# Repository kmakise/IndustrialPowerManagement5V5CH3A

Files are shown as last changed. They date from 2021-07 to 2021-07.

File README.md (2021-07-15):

# IndustrialPowerManagement5V5CH3A
基于STM32的电源控制器 使用LinerTechnology方案 Dwin屏交互 电流监控工作时间控制
# 图片
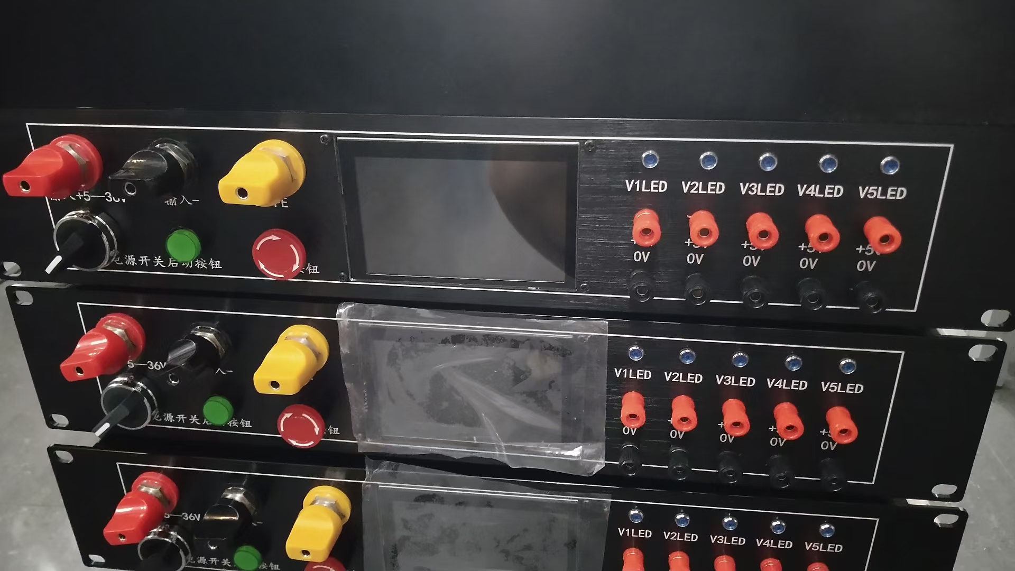
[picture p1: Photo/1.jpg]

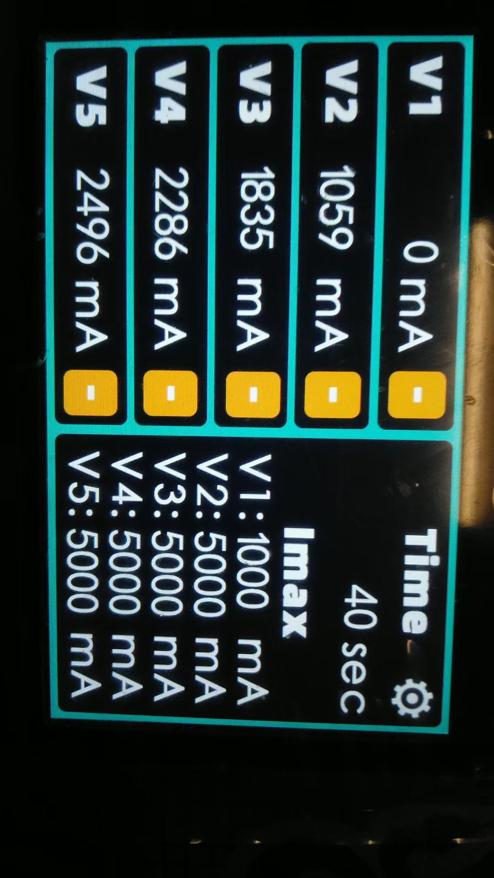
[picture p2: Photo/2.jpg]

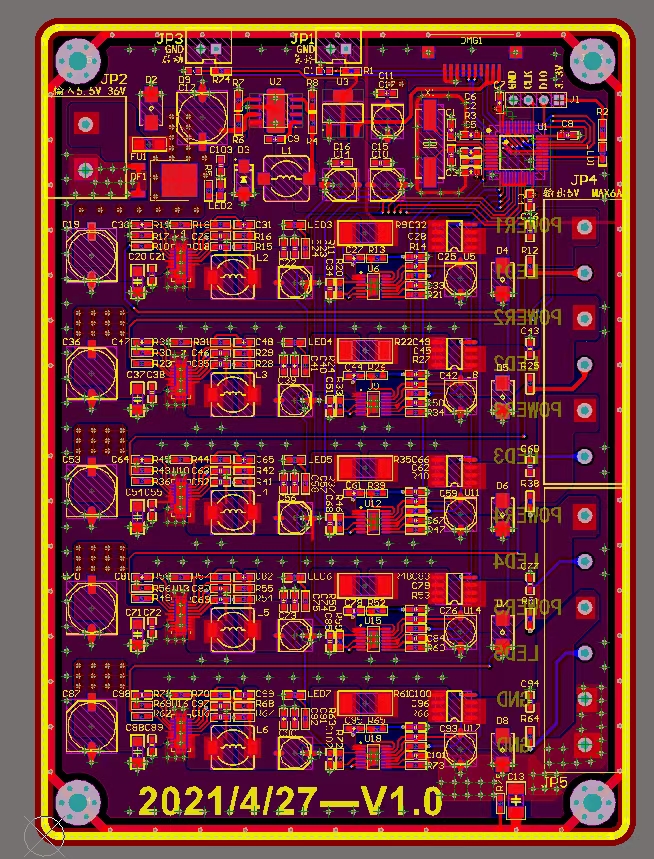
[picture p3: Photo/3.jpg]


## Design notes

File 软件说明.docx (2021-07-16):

# 1. 目录说明

目录\文件 名称 | 内容
DwinGUI\DWIN_SET | Dwin下载文件目录
DwinGUI\img | 界面图片目录
DwinGUI\DWprj.hmi | DGUSII工程
MCUProject\MDK-ARM\PowerManager.uvprojx | Stm32 MDK工程
MCUProject\PowerManager.ioc | Stm32 Cubemx工程
MCUProject\MDK-ARM\PowerManager\PowerManager.hex | STM32 Hex下载文件

# 2. 程序下载

## 2.1 DWIN

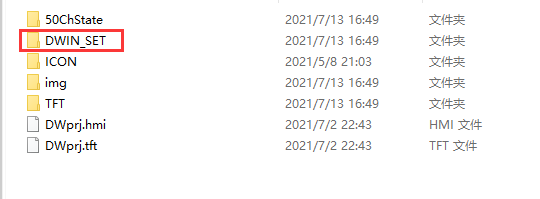
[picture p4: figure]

将 DWIN_SET 文件夹复制到SD卡根目录通过 SD 卡下载到屏里。顺序为：屏掉电——插卡——上电——蓝屏读 取 SD 卡内容，下载完成显示“SD Card Process …END！”——掉电、退出 SD 卡——上电。

## 2.2 STM32

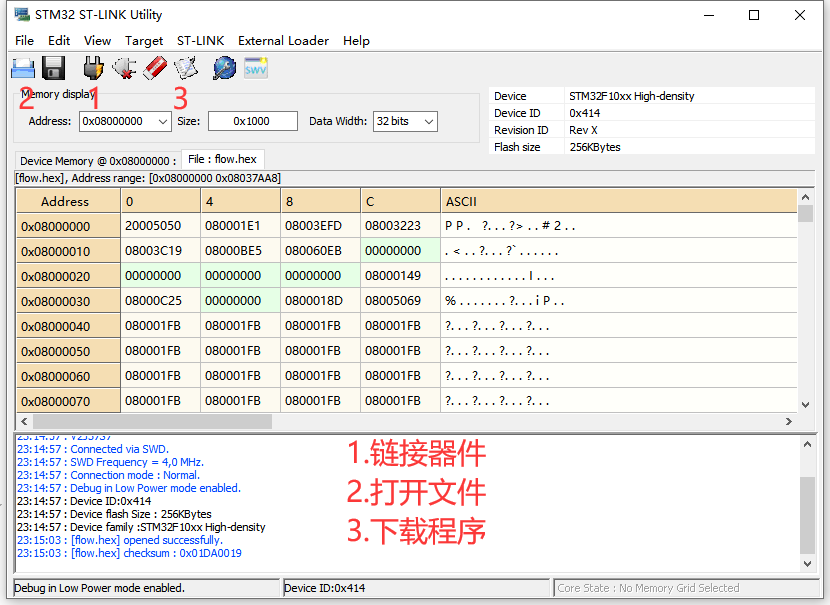
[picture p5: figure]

# 3. 电流校准

## 3.1 清除参数

将电流计算比例系数改为1.0后编译下载开始运行 Task01.c line77-81

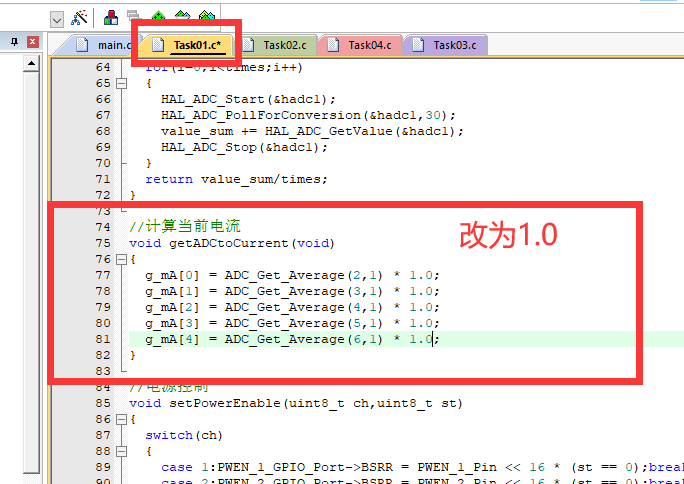
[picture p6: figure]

## 3.2 计算参数

例 修正系数=真实值/显示值 例：(实)2500/(显)1943=1.2866700977869274318

然后依次写入对应通道

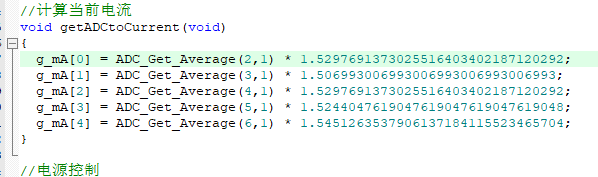
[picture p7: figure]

## 3.2 写入参数

重新编译并下载完成电流校准

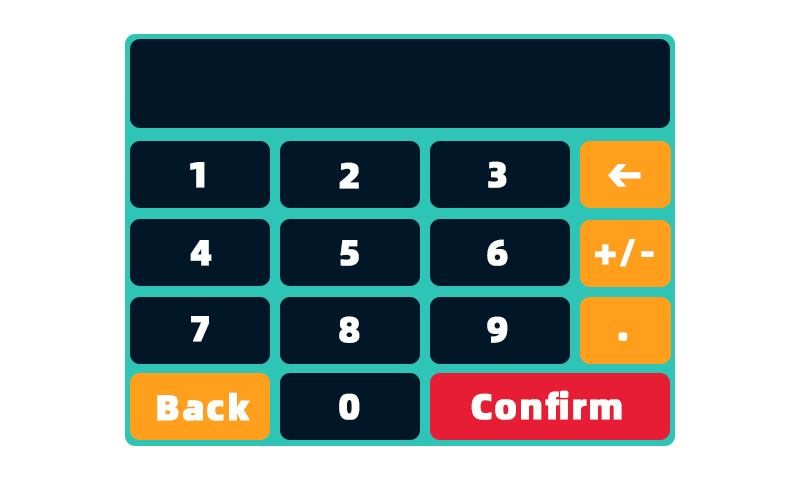
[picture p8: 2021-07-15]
DwinGUI/img/20键盘.png

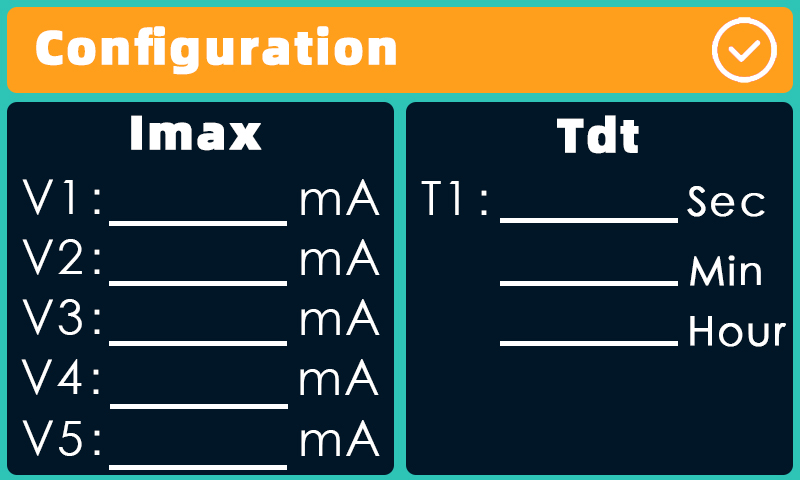
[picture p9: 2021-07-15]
DwinGUI/img/1Config.jpg

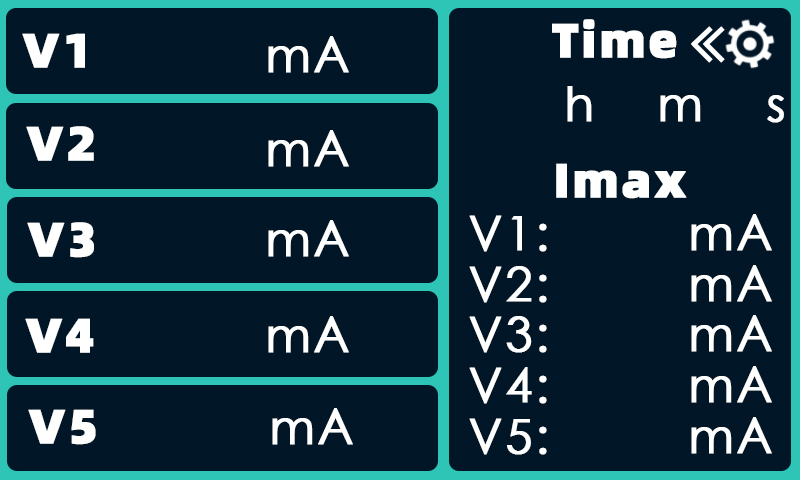
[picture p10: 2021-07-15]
DwinGUI/img/0主页面.jpg

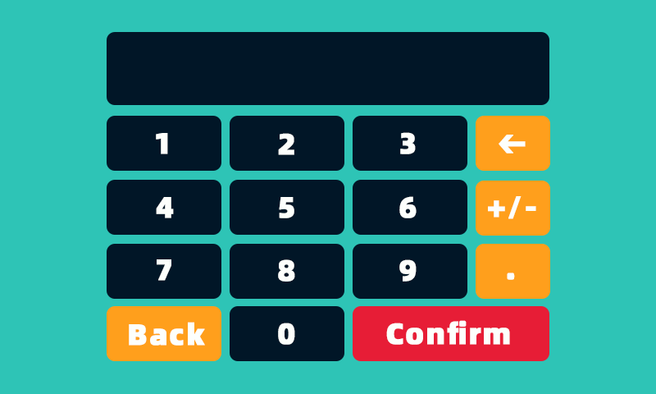
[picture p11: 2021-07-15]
DwinGUI/DWIN_SET/20键盘.png

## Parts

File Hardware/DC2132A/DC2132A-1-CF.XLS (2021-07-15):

Item | Qty | Reference | Part Description | Manufacturer / Part #
REQUIRED CIRCUIT COMPONENTS
1 | 12 | C3,C5,C6,C7,C9,C10,C11,C19,C20,C22,C27,C28 | Cap., X5R 10uF 50V 20% 1210 | TAIYO YUDEN UMK325BJ106MM-T
2 | 1 | C4 | Cap., X5R 0.1µF 50V 10% 0603 | TDK C1608X5R1H104K
3 | 1 | C12 | Cap., X5R 1uF 50V 10% 0603 | TDK C1608X5R1H105K
4 | 1 | C13 | Cap., NPO 1nF 25V 5% 0603 | AVX 06033A102JAT2A
5 | 1 | C14 | Cap., X5R 1µF 25V 10% 0603 | TDK C1608X5R1E105K
6 | 1 | C15 | Cap., X7R 0.1µF 25V 10% 0603 | AVX 06033C104KAT2A
7 | 2 | C17,C23 | Cap., X7R 0.01µF 100V 10% 0603 | AVX 06031C103KAT2A
8 | 1 | C21 | Cap., X7R 1µF 50V 10% 0805 | MURATA GRM21BR71H105KA12L
9 | 1 | C25 | Cap., X7R 1µF 16V 10% 0603 | MURATA GCM188R71C105KA64L
10 | 1 | C26 | Cap., X5R 10µF 6.3V 20% 0603 | TDK C1608X5R0J106M
11 | 1 | C29 | Cap., Alum. Elect. 100µF 35V ±20% F80 | Nippon Chemi-Con EMZA350ADA101MF80G
12 | 1 | D5 | Schottky Diode, 1A/40V SMA | DIODES/ZETEX B140-13-F
13 | 1 | L1 | Inductor, 5.5µH | WURTH ELECTRONIK 744325550
14 | 1 | L2 | Inductor, 470µH ±10% 1210 | MURATA LQH32CN471K23L
15 | 1 | Q1 | Transistor, NPN SOT23 | DIODES/ZETEX FMMT493TA
16 | 2 | Q2,Q3 | Transistor., PNP SOT23 | DIODES/ZETEX MMBT3906-7-F
17 | 1 | Q4 | MOSFET, Single P-Chan. 60V SOT-23 | VISHAY SI2309CDS-T1-GE3
18 | 1 | Q5 | Transistor, NPN SOT23 | CENTRAL SEMI. CORP. CMST3904TR
19 | 1 | R2 | Res., Chip 549 OHMS 0.10W 1% 0603 | VISHAY CRCW0603549RFKEA
20 | 1 | R5 | Res., Chip 499K 0.10W 1% 0603 | VISHAY CRCW0603499KFKEA
21 | 1 | R6 | Res., Chip 54.9K 0.10W 1% 0603 | VISHAY CRCW060354K9FKEA
22 | 2 | R7,R23 | Res., 0.010 OHMS 0.125W 1% 0805 | VISHAY WSL0805R0100FEA
23 | 1 | R8 | Res., Chip 3.92K 0.10W 1% 0603 | VISHAY CRCW06033K92FKEA
24 | 2 | R9,R26 | Res., Chip 10K 0.25W 5% 1206 | VISHAY CRCW120610K0JNED
25 | 1 | R12 | Res., Chip 100 OHMS 0.10W 1% 0603 | VISHAY CRCW0603100RFKEA
26 | 2 | R14,R18 | Res., Chip 4.99K 0.10W 1% 0603 | VISHAY CRCW06034K99FKEA
27 | 3 | R15,R29,R37 | Res., Chip 1.00K 0.10W 1% 0603 | VISHAY CRCW06031K00FKEA
28 | 2 | R17,R30 | Res., Chip 10.0K 0.10W 1% 0603 | VISHAY CRCW060310K0FKEA
29 | 1 | R20 | Res., Chip 60.4K 0.10W 1% 0603 | VISHAY CRCW060360K4FKEA
30 | 2 | R21,R38 | Res., Chip 100K 0.10W 1% 0603 | VISHAY CRCW0603100KFKEA
31 | 1 | R22 | Res., Chip 200 OHMS 0.125W 1% 0805 | VISHAY CRCW0805200RFKEA
32 | 1 | R24 | Res., Chip 47.5K 0.10W 1% 0603 | VISHAY CRCW060347K5FKEA
33 | 1 | R27 | Res., Chip 73.2K 0.10W 1% 0603 | VISHAY CRCW060373K2FKEA
34 | 1 | R28 | Res., Chip 11.3K 0.10W 1% 0603 | VISHAY CRCW060311K3FKEA
35 | 1 | R31 | Pot. 1 Turn 10K ±10% | BOURNS 91A1A-B28-A15L
36 | 1 | R32 | Pot. 1 Turn 5K ±10% | BOURNS 91A1A-B28-A13L
37 | 1 | R41 | Res., Chip 1K 0.10W 5% 0603 | VISHAY CRCW06031K00JNEA
38 | 1 | R42 | Res., Chip 1.47M 0.10W 1% 0603 | VISHAY CRCW06031M47FKEA
39 | 1 | R43 | Res., Chip 10K 0.10W 5% 0603 | VISHAY CRCW060310K0JNEA
40 | 1 | R44 | Res., Chip 280K 0.10W 1% 0603 | VISHAY CRCW0603280KFKEA
41 | 1 | R45 | Res., Chip 806K 0.10W 1% 0603 | VISHAY CRCW0603806KFKEA
42 | 1 | R47 | Res., Chip 5.1K 0.10W 5% 0603 | Vishay CRCW06035K10JNEA
43 | 1 | R48 | Res., Chip 2.7K 0.10W 5% 0603 | Vishay CRCW06032K70JNEA
44 | 2 | U1,U2 | I.C., Linear Reg. DD-R(07)(1462-REVF) | LINEAR TECH. CORP. LT3081ER#PBF
45 | 1 | U3 | I.C., Regulator QFN(28)(UDE)3MMX6MM | LINEAR TECH. CORP. LT8612EUDE#PBF
46 | 1 | U4 | I.C., DC/DC Converter DFN(08)(DD)3MMX3MM | LINEAR TECH. CORP. LT3092EDD#PBF
47 | 1 | U5 | I.C., Step-Down Converter DFN(08)(DD)3MMX3MM | LINEAR TECH. CORP. LTC3632EDD#PBF
OPTIONAL CIRCUIT COMPONENTS
1 | 1 | C8 | Cap., Alum 22µF 63V 25% | SUN Elect. Ind. 63CE22BS
2 | 0 | C16,C30 | OPTIONAL 0603
3 | 0 | C24 | OPTIONAL 1210
4 | 1 | D4 | LED, GRN | OSRAM Opto Semi. LG L29K-G2J1-24-Z
5 | 0 | R6,R19,R25,R46 | OPTIONAL 0603
6 | 1 | R13 | Res., Chip 549 OHMS 0.10W 1% 0603 | VISHAY CRCW0603549RFKEA
7 | 1 | R16 | Res/Jumper, Chip 0 Ohm 0.25W 0603 | VISHAY CRCW06030000Z0EA
8 | 0 | R33 | OPTIONAL Pot. 10 Turns 10K | BOURNS 3950S-1-103L
9 | 0 | R34 | OPTIONAL Pot. 10 Turns 5K | BOURNS 3950S-1-502L
HARDWARE
1 | 6 | E1,E2,E3,E4,E5,E6 | Turret, Testpoint | MILL-MAX 2501-2-00-80-00-00-07-0
2 | 2 | E7,E8 | Turret, Testpoint | MILL-MAX 2308-2-00-80-00-00-07-0
3 | 1 | JP1 | Headers, Dbl. Row 2 x 3 2mm Ctrs. | SAMTEC TMM-103-02-L-D
4 | 4 | J1,J2,J3,J4 | Connector, Banana Jack | KEYSTONE 575-4
5 | 1 | S1 | Switch Toggle, SPDT | Philmore, 30-10002B
6 | 1 | XJP1 | Shunt, 2mm Ctrs. | SAMTEC 2SN-BK-G

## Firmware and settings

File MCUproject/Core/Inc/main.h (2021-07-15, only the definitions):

#define IMON_1_Pin GPIO_PIN_2
#define IMON_1_GPIO_Port GPIOA
#define IMON_2_Pin GPIO_PIN_3
#define IMON_2_GPIO_Port GPIOA
#define IMON_3_Pin GPIO_PIN_4
#define IMON_3_GPIO_Port GPIOA
#define IMON_4_Pin GPIO_PIN_5
#define IMON_4_GPIO_Port GPIOA
#define IMON_5_Pin GPIO_PIN_6
#define IMON_5_GPIO_Port GPIOA
#define INP_1_Pin GPIO_PIN_7
#define INP_1_GPIO_Port GPIOA
#define INP_2_Pin GPIO_PIN_0
#define INP_2_GPIO_Port GPIOB
#define INP_3_Pin GPIO_PIN_1
#define INP_3_GPIO_Port GPIOB
#define INP_4_Pin GPIO_PIN_2
#define INP_4_GPIO_Port GPIOB
#define INP_5_Pin GPIO_PIN_10
#define INP_5_GPIO_Port GPIOB
#define RUN_LED_Pin GPIO_PIN_8
#define RUN_LED_GPIO_Port GPIOA
#define SW1_Pin GPIO_PIN_11
#define SW1_GPIO_Port GPIOA
#define SW2_Pin GPIO_PIN_12
#define SW2_GPIO_Port GPIOA
#define PWEN_1_Pin GPIO_PIN_5
#define PWEN_1_GPIO_Port GPIOB
#define PWEN_2_Pin GPIO_PIN_6
#define PWEN_2_GPIO_Port GPIOB
#define PWEN_3_Pin GPIO_PIN_7
#define PWEN_3_GPIO_Port GPIOB
#define PWEN_4_Pin GPIO_PIN_8
#define PWEN_4_GPIO_Port GPIOB
#define PWEN_5_Pin GPIO_PIN_9
#define PWEN_5_GPIO_Port GPIOB

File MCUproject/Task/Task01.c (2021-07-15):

/**
  ******************************************************************************
  * File Name          : Task01.c
  * Description        : Code for freeRTOS Task01 Application
  ******************************************************************************
  * @author  kmakise
  * @version V1.0.0
  * @date    2021-6-2
  * @brief   Power Management Main Logic
	******************************************************************************
  * @attention
  * <h2><center>&copy; Copyright (c) kmakise
  * All rights reserved.
  *
  *
  ******************************************************************************
  */
/* Includes ------------------------------------------------------------------*/
#include "main.h"
#include "cmsis_os.h"
#include "adc.h"
#include "usart.h"
#include "gpio.h"
#include "Task01.h"
#include "Task02.h"
#include "Task03.h"
#include "Task04.h"

/*Global Data Space ----------------------------------------------------------*/

uint16_t g_mA[5] = {0,0,0,0,0};
uint16_t g_chst[5] = {WARITING,WARITING,WARITING,WARITING,WARITING};
uint16_t g_state = 0; //0 等待状态 1运行状态 2超限状态 3急停状态

/*Driver Function ------------------------------------------------------------*/

uint8_t getRunPress(void)
{
	return (SW2_GPIO_Port->IDR & SW2_Pin) == 0;
}
uint8_t getStopPress(void)
{
	return (SW1_GPIO_Port->IDR & SW1_Pin) == 0;
}

//ch(1-6Chnnal),times(读取次数)
uint32_t ADC_Get_Average(uint8_t ch,uint8_t times)
{
	ADC_ChannelConfTypeDef sConfig;		//通道初始化
	uint32_t value_sum=0;	
	uint8_t i;
	switch(ch)							//选择ADC通道
	{
		case 1:sConfig.Channel = ADC_CHANNEL_1;break;	
		case 2:sConfig.Channel = ADC_CHANNEL_2;break;
		case 3:sConfig.Channel = ADC_CHANNEL_3;break;
		case 4:sConfig.Channel = ADC_CHANNEL_4;break;
		case 5:sConfig.Channel = ADC_CHANNEL_5;break;
		case 6:sConfig.Channel = ADC_CHANNEL_6;break;
	}
	sConfig.SamplingTime = ADC_SAMPLETIME_239CYCLES_5;
	sConfig.Rank = 1;
	HAL_ADC_ConfigChannel(&hadc1,&sConfig);											
	for(i=0;i<times;i++)
	{
		HAL_ADC_Start(&hadc1);		
		HAL_ADC_PollForConversion(&hadc1,30);	
		value_sum += HAL_ADC_GetValue(&hadc1);			
		HAL_ADC_Stop(&hadc1);	
	}
	return value_sum/times;
}

//计算当前电流
void getADCtoCurrent(void)
{
	g_mA[0] = ADC_Get_Average(2,1) * 1.0;
	g_mA[1] = ADC_Get_Average(3,1) * 1.506993006993006993006993006993;
	g_mA[2] = ADC_Get_Average(4,1) * 1.5297691373025516403402187120292;
	g_mA[3] = ADC_Get_Average(5,1) * 1.5244047619047619047619047619048;
	g_mA[4] = ADC_Get_Average(6,1) * 1.5451263537906137184115523465704;
}

//电源控制
void setPowerEnable(uint8_t ch,uint8_t st)
{
	switch(ch)
	{
		case 1:PWEN_1_GPIO_Port->BSRR = PWEN_1_Pin << 16 * (st == 0);break;
		case 2:PWEN_2_GPIO_Port->BSRR = PWEN_2_Pin << 16 * (st == 0);break;
		case 3:PWEN_3_GPIO_Port->BSRR = PWEN_3_Pin << 16 * (st == 0);break;
		case 4:PWEN_4_GPIO_Port->BSRR = PWEN_4_Pin << 16 * (st == 0);break;
		case 5:PWEN_5_GPIO_Port->BSRR = PWEN_5_Pin << 16 * (st == 0);break;
	}
}

//输出控制
void setOutputEnable(uint8_t ch,uint8_t st)
{
	switch(ch)
	{
		case 1:INP_1_GPIO_Port->BSRR = INP_1_Pin << 16 * (st == 0);break;
		case 2:INP_2_GPIO_Port->BSRR = INP_2_Pin << 16 * (st == 0);break;
		case 3:INP_3_GPIO_Port->BSRR = INP_3_Pin << 16 * (st == 0);break;
		case 4:INP_4_GPIO_Port->BSRR = INP_4_Pin << 16 * (st == 0);break;
		case 5:INP_5_GPIO_Port->BSRR = INP_5_Pin << 16 * (st == 0);break;
	}
}

void PowerEN(uint8_t st)
{
	setPowerEnable(1,st);
	setPowerEnable(2,st);
	setPowerEnable(3,st);
	setPowerEnable(4,st);
	setPowerEnable(5,st);
}

void OutputEN(uint8_t st)
{
	setOutputEnable(1,st);
	setOutputEnable(2,st);
	setOutputEnable(3,st);
	setOutputEnable(4,st);
	setOutputEnable(5,st);
}
/*State function --------------------------------------------------------------*/

//等待状态的按键事件
void ST0_Wait_keyEvent(void)
{
	//急停
	if(!getStopPress())
	{
		if(getRunPress())
		{
			setBeepState(1);			//蜂鸣器控制输出
			while(getRunPress());	//等待释放按键
			setTimeVal(CfgData.dt);	//设置倒计时时间
			setTimeState(SET);		//开始倒计时
			g_state = 1;					//跳转状态
			for(int i = 0;i < 5;i++) 
			{
				g_chst[i] = RUNNING;//设置通道状态
			}
			OutputEN(ENABLE);			//配置输出
		}
	}
	else
	{
		if(getRunPress())
		{
			setBeepState(3);
		}
	}

}

//运行状态 等待时间结束 电流超限 急停
void ST1_Run_JumpEvent(void)
{
	//停止
	if(getRunPress())
	{
		setBeepState(1);				//蜂鸣器控制输出
		while(getRunPress());		//等待释放按键
		OutputEN(DISABLE);			//关闭输出
		setTimeState(RESET);		//关闭倒计时
		for(int i = 0;i < 5;i++) 
		{
			g_chst[i] = WARITING;	//设置通道状态
		}
		g_state = 3;						//跳转状态
	}
	
	//等待时间结束
	if(getTimeVal() == 0)
	{
		setBeepState(1);				//蜂鸣器控制输出
		OutputEN(DISABLE);			//关闭输出
		setTimeState(RESET);		//关闭倒计时
		setTimeVal(CfgData.dt);		//重新设置倒计时时间
		for(int i = 0;i < 5;i++) 
		{
			g_chst[i] = WARITING;	//设置通道状态
		}
		g_state = 0;						//跳转状态
	}
	
	//电流超过限制
	uint8_t oc = 0;
	for(int i = 0;i < 5;i++)
	{
		if(g_mA[i] > CfgData.octh[i])
		{
			oc = 1;
		}
	}
	if(oc)
	{
		setBeepState(3);				//蜂鸣器控制输出
		OutputEN(DISABLE);			//关闭输出
		setTimeState(RESET);		//关闭倒计时
		for(int i = 0;i < 5;i++) 
		{
			g_chst[i] = WARITING;	//设置通道状态
		}
		for(int i = 0;i < 5;i++)
		{
			if(g_mA[i] > CfgData.octh[i])
			{
				g_chst[i] = CAUTION;	//设置通道状态
			}
		}
		g_state = 2;						//跳转状态
	}
	
	//急停
	if(getStopPress())
	{
		setBeepState(1);				//蜂鸣器控制输出
		OutputEN(DISABLE);			//关闭输出
		setTimeState(RESET);		//关闭倒计时
		for(int i = 0;i < 5;i++) 
		{
			g_chst[i] = WARITING;	//设置通道状态
		}
		while(getStopPress())		//等待释放
		{
			if(getRunPress())
			{
				setBeepState(3);
			}
			osDelay(20);
		}
		g_state = 3;						//跳转状态
	}	
}

//等待重新配置并开始
void ST2_OC_JumpEvent(void)
{
	if(getRunPress())
	{
		setBeepState(2);				//蜂鸣器控制输出
		while(getRunPress());		//等待释放按键
		OutputEN(DISABLE);			//关闭输出
		setTimeState(RESET);		//关闭倒计时
		setTimeVal(CfgData.dt);		//重新设置倒计时时间
		for(int i = 0;i < 5;i++) 
		{
			g_chst[i] = WARITING;	//设置通道状态
		}
		g_state = 0;						//跳转状态
	}
}
//等待重新配置并开始
void ST3_STOP_JumpEvent(void)
{
	if(getRunPress())
	{
		setBeepState(2);				//蜂鸣器控制输出
		while(getRunPress());		//等待释放按键
		OutputEN(DISABLE);			//关闭输出
		setTimeState(RESET);		//关闭倒计时
		setTimeVal(CfgData.dt);		//重新设置倒计时时间
		for(int i = 0;i < 5;i++) 
		{
			g_chst[i] = WARITING;	//设置通道状态
		}
		g_state = 0;						//跳转状态
	}
}

/*State Machine ---------------------------------------------------------------*/

//运行状态监控状态机
void runningStateMachine(void)
{
	switch(g_state)//0 等待状态 1运行状态 2超限状态 3急停状态
	{
		case 0://等待状态 
		{
			setTimeVal(CfgData.dt);	//设置倒计时时间
			getADCtoCurrent();
			ST0_Wait_keyEvent();
			break;
		}
		case 1://运行状态 
		{
			getADCtoCurrent();
			ST1_Run_JumpEvent();
			break;
		}
		case 2://超限状态
		{
			//等待重新配置并开始
			ST2_OC_JumpEvent();
			break;
		}
		case 3://急停状态
		{
			//等待重新配置并开始
			ST3_STOP_JumpEvent();
			break;
		}
	}
}

void Task01Main(void)
{
	osDelay(100);
	//outputTest();
	
	//关闭各个通道输出
	OutputEN(DISABLE);
	
	//打开各个通道电源
	PowerEN(ENABLE);
	
	//显示倒计时
	setTimeState(RESET);	//关闭倒计时
	setTimeVal(CfgData.dt);	//设置倒计时时间
	
	setTimeState(RESET);
	for(;;)
	{
		runningStateMachine();
		osDelay(10);
	}
}

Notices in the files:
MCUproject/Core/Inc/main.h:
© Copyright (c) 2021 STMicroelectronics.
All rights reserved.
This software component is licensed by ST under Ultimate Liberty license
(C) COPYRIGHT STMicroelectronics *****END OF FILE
